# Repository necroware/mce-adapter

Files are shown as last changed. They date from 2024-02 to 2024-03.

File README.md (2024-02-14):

# MCE Adapter (Prototype!)

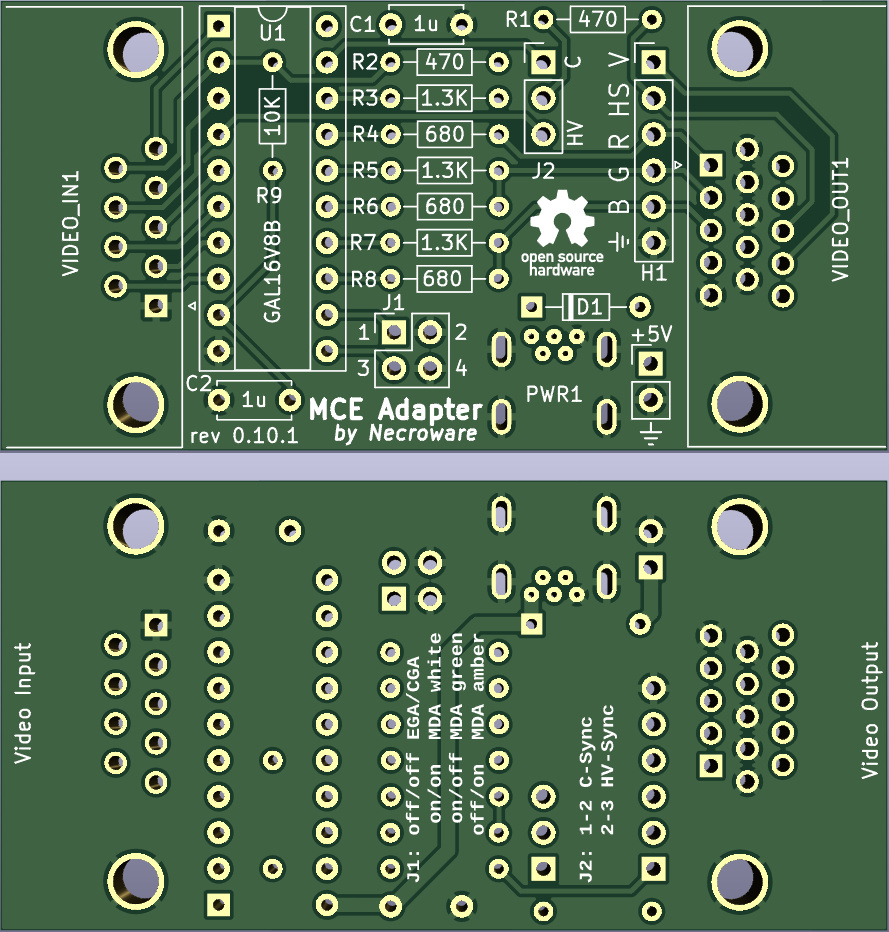
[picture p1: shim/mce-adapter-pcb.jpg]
MCE Adapter


The MCA-Adapter is a device, which can convert MDA (and Hercules), EGA and CGA
to analogue RGBS signal. It supports following features.

- Converts digital MDA, Hercules, CGA and EGA to analog RGBS or RGBHV/VGA signal
- Color DAC for 3, 4, 16 and 64 color modes
- Switchable composite sync from H- and V-Sync
- Loop through HV-Sync, colors conversion only mode
- Includes IBM's "brown-hack"for CGA and 16-colors EGA modes
- Hi/Low resolution EGA mode autodect for proper color representation
- Switchable green, white and amber monochrome screen emulation

Youtube Videos:
- Part 1: Why GBS-8200 is not a CGA/EGA converter https://youtu.be/7c3yLX52ZEs
- Part 2: Theory and implementation https://youtu.be/aUFKB4b5KpE
- Part 3: Showtime https://youtu.be/F1685u-QQ0k

## Why did I make this?

Because why not? I wanted to get some practice with EDA and I needed such an
adapter to test some of my old graphics cards.

## Why might somebody need this?

If you want to connect your old PC with MDA, CGA or EGA graphics to a more
modern VGA display, it's going to be difficult. First of all, this old graphics
standards are digital, so RGB information is sent as a bunch of 1 and 0. VGA on
the other hand understands only analogue signals, so f.e. the intensity of the red
color is defined by some value between two voltages and not by a discrete value.
So the first job of this adapter is to translates digital video signals into
analogue video signals. However, this is may be not enough, since the horizontal
sync signal of the old video standards is not supported by a usual VGA monitor.
For this purpose, a very famous upscaler named GBS-8200 and compatible can be
used to convert the sync signal to VGA compatible level.  However, GBS-8200
expects such called composite sync signal, where horizontal and vertical sync
signals are combined. This is, where this adapter comes into place, it doesn't
only convert digital RGB signal to analogue, but also composite sync signal from
incoming horizontal and vertical signals. Long story short, you will need this
adapter to connect a MDA, CGA or EGA graphics card to an analogue RGB monitor,
either by using GBS-8200 converter or the adapter standalone, in case your
monitor supports horizontal frequencies down to 15kHz.

## Why didn't I take an existing solution?

Well, first of all, I wanted to gain some experience in this. Second, I actually
was heavily inspired by a YouTube video by TheRasteri, where he evaluates the
output possibilities of an old PC, talks about the technical background and
creates his own adapter. You can see the video here:

* Part 1: https://www.youtube.com/watch?v=kHhpTq-WSJk
* Part 2: https://www.youtube.com/watch?v=vwKA1z8tg1g

As I saw his solution with a ROM, I instantly thought, that the same thing can
be done using a programmable logic IC, like GAL16V8. It would have some benefits
in timing behaviour over a solution with ROM and be also very flexible. So, here
it is.

## Which modes does it support?

The adapter can convert MDA, Hercules, CGA, 16 colors EGA and 64 colors EGA to
standard VGA (RGBHV) or RGBS (combined HV-sync). The sync output frequency is
always the same as the input frequency. The adapter can only compose HV-sync,
but doesn't actively change it. The digital color signal is converted to analogue
color signal, so any analogue RGB monitor should understand it.

## Jumpers and switches

ATTENTION: Jumper settings changed compared to previous revisions 

Color mode selection J1:
Mode                       | 1-2 | 3-4 
---------------------------|-----|-----
CGA/EGA (15kHz / 21kHz)    | OFF | OFF 
MDA/Hercules white (18kHz) | ON  | ON
MDA/Hercules green (18kHz) | ON  | OFF
MDA/Hercules amber (18kHz) | OFF | ON

Sync selectiom J2:
Mode               | Setting
-------------------|----------
HV-Sync (VGA)      | 1-2
C-Sync (Composite) | 2-3

## How to use this stuff?

1. Take the gerber files and make a PCB.
2. Assemble the board
3. Compile code/mceplug.eqn using EQN2JED tool
4. Write the compiled jed file to a GAL16V8 IC
5. Put it into the board and connect the cables
   f.e. CGA -> MCE Adapter -> GBS-8200 -> Analog RGB Monitor

## Bill of materials

Reference  |#  |LCSC    |Description
-----------|---|--------|-------------------------------------
C1 C2      |2  |C2839237|capacitor 1µF
D1         |1  |C402218 |diode 1N5819
H1         |1  |C492405 |pin header 1x6
J1         |1  |C492419 |pin header 2x2
J2         |1  |C429954 |pin header 1x3
PWR1       |1  |C46398  |USB-B mini port
PWR2       |1  |C152154 |pin header 1x2 (+5V connector)
R1 R2      |2  |C119317 |resistor 470 Ohm
R3 R5 R7   |3  |C2848597|resistor 1.3k Ohm
R4 R6 R8   |3  |C119320 |resistor 680 Ohm
R9         |1  |C173139 |resistor 10k Ohm
U1         |1  |C6509   |GAL16V8B (or compatible)
VIDEO_IN1  |1  |C141882 |DB9 female connector (MDA/EGA/CGA)
VIDEO_OUT1 |1  |C75754  |DIB15 female connector (VGA)

## Tested with following monitors
- GBS-8200 with original hardware (only 15kHz modes work)
- GBS-8200 with gbs-control firmaware (Hercules and hi-res EGA sync unstable)
- NEC Multisync LCD1970NX 19" TFT (everything works fine, Hercules is not in full screen, but works stable)
- EIZO L365 15" TFT (only Hi-Res EGA works, doesn't support 15kHz CGA nor 50Hz Hercules)
- Benq BL702A

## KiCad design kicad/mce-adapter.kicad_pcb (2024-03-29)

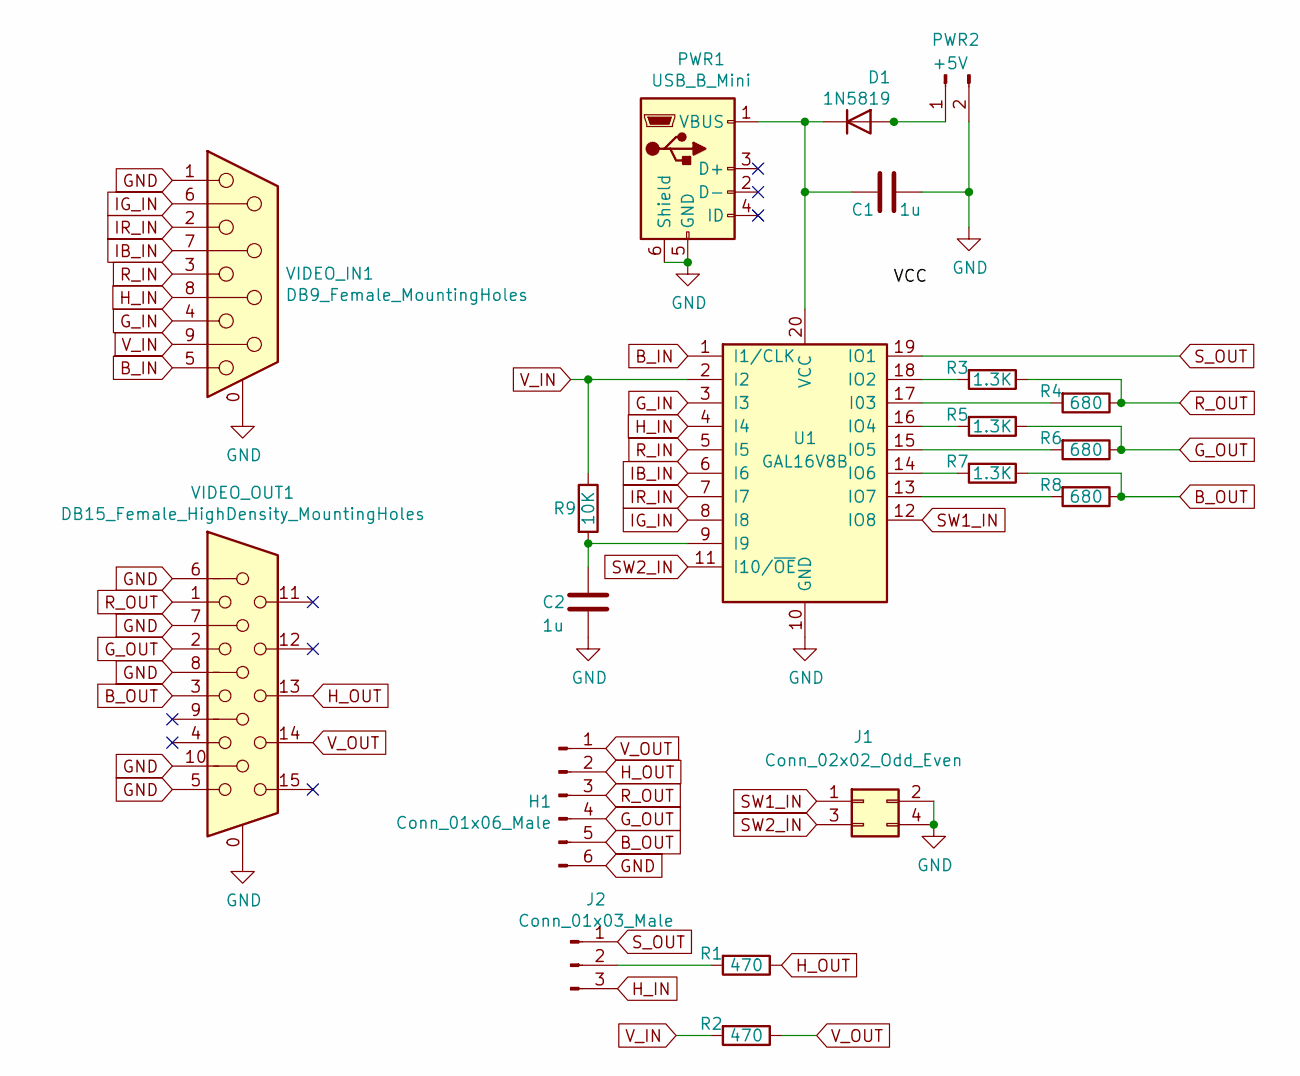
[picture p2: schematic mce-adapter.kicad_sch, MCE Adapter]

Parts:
C1, C2: 1u; C_Disc_D5.0mm_W2.5mm_P5.00mm; LCSC C2839237
D1: 1N5819; D_DO-34_SOD68_P7.62mm_Horizontal; LCSC C402218
H1: Conn_01x06_Male; PinHeader_1x06_P2.54mm_Vertical; LCSC C492405
J1: Conn_02x02_Odd_Even; PinHeader_2x02_P2.54mm_Vertical; LCSC C492419
J2: Conn_01x03_Male; PinHeader_1x03_P2.54mm_Vertical; LCSC C429954
PWR1: USB_B_Mini; USB_Mini-B-Jing_Extension_LSCS_C46398; LCSC C46398
PWR2: +5V; PinHeader_1x02_P2.54mm_Vertical; LCSC C152154
R1, R2: 470; R_Axial_DIN0204_L3.6mm_D1.6mm_P7.62mm_Horizontal; LCSC C119317
R3, R5, R7: 1.3K; R_Axial_DIN0204_L3.6mm_D1.6mm_P7.62mm_Horizontal; LCSC C2848597
R4, R6, R8: 680; R_Axial_DIN0204_L3.6mm_D1.6mm_P7.62mm_Horizontal; LCSC C119320
R9: 10K; R_Axial_DIN0204_L3.6mm_D1.6mm_P7.62mm_Horizontal; LCSC C173139
U1: GAL16V8B; DIP-20_W7.62mm_Socket; LCSC C6509
VIDEO_IN1: DB9_Female_MountingHoles; DSUB-9_Female_Horizontal_P2.77x2.84mm_EdgePinOffset7.70mm_H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; LCSC C141882
VIDEO_OUT1: DB15_Female_HighDensity_MountingHoles; DSUB-15-HD_Female_Horizontal_P2.29x1.98mm_EdgePinOffset8.35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; LCSC C75754

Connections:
B_IN: U1.1 (I1/CLK), VIDEO_IN1.5
B_OUT: H1.5, R7.1, R8.1, VIDEO_OUT1.3
GND: C1.2, C2.2, H1.6, J1.2, J1.4, PWR1.5 (GND), PWR1.6 (Shield), PWR2.2, U1.10 (GND), VIDEO_IN1.0 (PAD), VIDEO_IN1.1, VIDEO_OUT1.0, VIDEO_OUT1.5, VIDEO_OUT1.6, VIDEO_OUT1.7, VIDEO_OUT1.8, VIDEO_OUT1.10
G_IN: U1.3 (I3), VIDEO_IN1.4
G_OUT: H1.4, R5.1, R6.1, VIDEO_OUT1.2
H_IN: J2.3, U1.4 (I4), VIDEO_IN1.8
H_OUT: H1.2, R1.1, VIDEO_OUT1.13
IB_IN: U1.6 (I6), VIDEO_IN1.7
IG_IN: U1.8 (I8), VIDEO_IN1.6
IR_IN: U1.7 (I7), VIDEO_IN1.2
unnamed: D1.2 (A), PWR2.1
unnamed: C1.1, D1.1 (K), PWR1.1 (VBUS), U1.20 (VCC)
unnamed: J2.2, R1.2
unnamed: R4.2, U1.17 (I03)
unnamed: C2.1, R9.2, U1.9 (I9)
unnamed: R3.2, U1.18 (IO2)
unnamed: R5.2, U1.16 (IO4)
unnamed: R6.2, U1.15 (IO5)
unnamed: R7.2, U1.14 (IO6)
unnamed: R8.2, U1.13 (IO7)
R_IN: U1.5 (I5), VIDEO_IN1.3
R_OUT: H1.3, R3.1, R4.1, VIDEO_OUT1.1
SW1_IN: J1.1, U1.12 (IO8)
SW2_IN: J1.3, U1.11 (I10/~OE)
S_OUT: J2.1, U1.19 (IO1)
V_IN: R2.2, R9.1, U1.2 (I2), VIDEO_IN1.9
V_OUT: H1.1, R2.1, VIDEO_OUT1.14

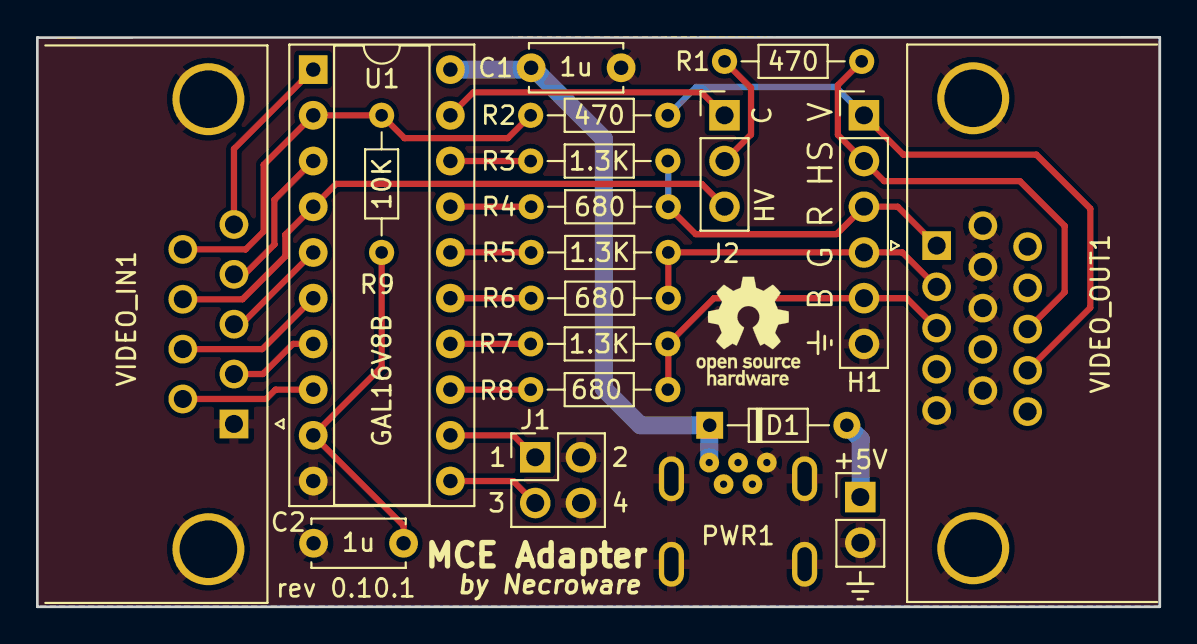
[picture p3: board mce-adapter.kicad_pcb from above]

Board: 2 copper layers, 62.4 x 31.6 mm, 20 parts (0 on the bottom side), 27 nets.

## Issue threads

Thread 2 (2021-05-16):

Add documentation for compiling and programming

wsuchy, 2021-05-16:
It would be useful to have the README file include at least the name of the basic tool chain and programmer
for the GAL chip.

necroware, 2021-05-16:
The name of the tool is included in the readme already, its EQN2JED. It's a tool, which you usually have to pay for, but ask google and may be it will tell you how to work around this problem ;) I wrote my own compiler for for the GAL, but it still doesn't support some features and is not yet well tested. May be one day I'll find the time to get it in shape and open source it. As for the programmer, there are hundreds of devices. I'm using TL866II+, but you are not limited by that. Just use whatever you have.

necroware, 2021-05-16:
Oh, almost forgot it, if you don't know how to compile the code, just use the compiled file from the release. You don't have to mess around with EQN2JED, if you don't want to change anything.

wsuchy, 2021-05-19:
Great, thank you for clarifying! BTW You could do a series about GALs on YouTube as I couldn't find any decent tutorial for beginners. I think that FPGAs have replaced them in the modern world.

necroware, 2021-05-19:
Yes GALs were replaced by FPGAs in most cases. But you still need GALs, if you work with retro hardware, that's why I was tinkering a lot with them. Yes, may be I'll do a special on GALs one day....

Closed 2021-05-19.

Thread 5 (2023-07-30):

1N5819 VIA's are not large enough. VGA Connector row spacing incorrect, Cap Incorrect

oXL0C0Xo, 2023-07-30:
Couple issues that I noticed while trying to build this.

The VIA's for the 1N5819 are too small, they should be the same size as the hole for the pin header or socket. I have ordered 2 different 1N5819 and both of them have thicker leads than a 1/4w resistor

The footprint for the VGA connector is incorrect, the rows of 5 are too close together, unless you are using some type of uncommon connector that I cant find.

The capacitor that you have listed in the BOM is 10x13 with 5mm lead spacing. The footprint on the PCB is 5mm diameter with a 2.5mm lead spacing

Appreciate your work on this project! Thanks again!

19MiRa90, 2023-08-03:
My 1N5819 fits.
There are 2 different D-SUB HD Socket. If you have not the smaller one you can push the outer pins 1-2mm to the inner
Use any very small one, 10-100µF is ok.

oXL0C0Xo, 2023-08-06:
I didn't need help with hacks to make it work, I was just pointing out the issues I encountered in case someone capable of fixing the issues wants to do it for the next guy before they order the incorrect parts. Regardless if there are other parts that work, the part numbers in the BOM are incorrect.

SteveGuidi, 2023-10-15:
> Regardless if there are other parts that work, the part numbers in the BOM are incorrect.

Just came across this post before ordering components -- has the BOM has been updated with parts that fit the footprints on the PCB?

SteveGuidi, 2023-11-23:
I redrew the PCB in EasyEDA and corrected the footprints noted in this thread; see link to project below.  I also replaced the mini-USB connector with a similar-sized micro-usb for personal preference.

Sorry, I'm not familiar with the KiCad stack and there were several non-trivial updates needed for the project to work with the current version.

https://oshwlab.com/sguidi/mce-adapter

necroware, 2024-02-14:
I took the default VGA port footprint from KiCad and it seems to be slightly off indeed. Nothing critical, but a little bit fiddly when inserting the port indeed. I slightly readjusted the footprint on the next revision.

Closed 2024-02-14.

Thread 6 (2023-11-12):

Potential improvement: power to VGA pin 9 for SCART blanking

SanguineBrah, 2023-11-12:
If you ever make another revision of this board, it might be worth adding a jumper to enable/disable sending 5v to pin 9 of the VGA connector. This would make it possible to use a VGA to SCART cable with a 100ohm resistor to the SCART RGB blanking pin (16) to deliver CGA to a standard European television.

This should be implemented as a jumper because there are reported to be some rare older monitors from when pin 9 was a key pin that mistakenly ground it rather than leaving it N/C.

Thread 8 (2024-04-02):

Potential improvement: selectable sync-on-green output

Leo-PL, 2024-04-02:
This would allow for easier connecting to scaler devices other than GBS8200, which sometimes have a RGB on triple-RCA component video connector, accepting either RGB or YPbPr.

While the latter is overkill, due to requiring high-speed video opamps to convert that, sync-on-green can be done with two transistors and some passives. Then, any cheap VGA-to-3RCA adapter normally used for YPbPr input should work with that.

I plan to connect a small external circuit to the pin-header exposing the signals as a PoC - and if it works out, I can implement that on the board and submit a PR.

Leo-PL, 2024-04-04:
I did a little testing today, and it won't be as easy. This is because black level at the output is at 0V because of lack of bias - so even if I add transistor to shunt the signal when the extracted composite sync is active, there is nothing to shunt. I'll probably try to bodge on some resistors to +5V, to shift the black level and if that works out, try to add this to board design, most likely implementing #6 as well, as I'd like to use SCART-equipped displays too.

Leo-PL, 2024-04-05:
I did some more digging around, and it seems that RGB (or YPbPr) with sync-on-green in general uses negative pulses to indicate sync, so this is better off done with an external device.

Closed 2024-04-05.

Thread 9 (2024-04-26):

Production via PCBWay is not possible

oe3gwu, 2024-04-26:
I got this email today. I wanted 5 (min qty) of those adapters fully assembled.

Could you please update your BOM File please?

```
Hi,
Thank you for choosing PCBWay! I'm your sales representative.
There is a question for you about your inquiry:
The part number in your BOM file is uncompleted, so we can't quote for you according to this file.
Could you pls complete them and send the file to us again?
There is a sample BOM file attached for reference.
Thank you and look forward to your reply!
2024-04-26
-----------------------------------
Best Regards
Kingsely

Customer Service Executive
PCBWay Production Range: PCB/PCB Assembly/Components Purchasing/CNC/3D Printing
[Skype: live:cqq13706811944](skype:Pcbwayservice03) | [Tel:86-571-8](tel:86-571-85317569)7093808
Email: [service22@pcbway.com](mailto:service03@pcbway.com)| Register: www.pcbway.com/2p
Mon.-Fri. 9:00-12:00,13:30-18:00; Sat. 9:00-12:00 (China, UTC/GMT +8.00)
```

Closed 2025-02-03.

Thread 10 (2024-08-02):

Auto mode detection filter doesn't work in CGA mode for C-Sync with C2=1uF

yngwiechou, 2024-08-02:
It seems C2 = 1uF is too low for C-Sync to work properly.

Please see attached graph
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

Apology for not able to test MDA and Enhanced EGA, since I don't have them in hand.

Liz1701, 2025-01-31:
Hi, I don't understand all the technical stuff.  I built one of these from kit.  I have an LCD that works with the 15khz RGBHV.  However I'm wandering if I'm having the C-Sync Issue you describe?  My purpose in getting the MCE adapter was to connect my Sony PVM1350.  But it apparently isn't detecting the RGBs 15khz.  This is using CGA.

oXL0C0Xo, 2025-02-03:
Has anyone tested if swapping the capacitor at C2 with a 4.7uf resolves the issue without any negative effects on anything else?

necroware, 2025-02-09:
I tested 4.7uf and it seems to work fine. Other features were not affected. Color mode auto-detection works fine.

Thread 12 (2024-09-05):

CGA, Hi-res EGA detection doesn't work.

A-Small-Mice, 2024-09-05:
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

I used the MCE adapter with an IBM EGA card.

The IBM EGA card's jumper settings are set to EGA monitor.

necroware, 2025-02-03:
This one could be a duplicate of #10

A-Small-Mice, 2025-02-07:
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

Thank you for answering my question. Since it has been quite a long time since I raised this issue, I took a moment to think about why I determined that the EGA detection was not functioning correctly.

It is probably because there is a difference between the images in the demonstration video you uploaded and mine. When comparing my image with yours, I can see that some colors are missing in my image.

necroware, 2025-02-07:
Ok, that looks odd indeed. I didn't realize it on the previous image. Which firmware and adapter version did you use? I just tried the latest release and couldn't reproduce the issue. This is definitely not related to Hi-Res EGA detection, because we can clearly see that the brown colors are right. That is a reliable sign for working automatic mode switching. So there has to be something else what is wrong, but currently I don't know what exactly.

Can you play with contrast settings of your monitor? Do you see more/less pixels if you adjust  that?

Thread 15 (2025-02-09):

TTL signal level for sync signals

necroware, 2025-02-09:
On VGA the color signals are analog values between 0V and 0.7V (actually all monitors are at least 1V tolerant) but the HV-Sync values should be at TTL levels between 0V and 5V. Unfortunately some devices are not 5V tolerant and could be damaged over time when using normal TTL levels. One of such devices is GBS-8200, which is only 3.3V tolerant.

In the past I experimented with different levels and it tuned out that all of the monitors and converters which I tested did actually work with the same levels for colors and sync signals with up to 1V, so I've chosen the resistors accordingly to stay under 1V for all signals.

Recently I saw slight instability on the H-Sync on some monitors when the computer attached was under load. A slight blurry shift at particular frequency. This is most probably because the H-Sync gets disturbed/unstable. Probably this can be mitigated by raising voltage levels of the sync signals.

Going up to 5V would be VGA specification conform, but as I wrote, some devices don't like it. The best would be to try to stay below 3.3V. This can be achieved by replacing 470 Ohm resistors R1 and R2 with 33 Ohm values.

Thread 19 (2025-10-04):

Self Powered from rectified sync signals

pgodwin, 2025-10-04:
Curious if you've considered making the device self-powered by rectifying the sync signals? Similar to https://www.mikesarcade.com/wiretap/info/SyncInv.pdf

I have it ago and seem to get about 4V from HS and VS but it looks like the current design draws about 20mA which is too high. So thinking something like the ATF16LV8C could be used instead and provide a great operating voltage range.

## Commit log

2020-10-15 Added rev0.5
    [Gerber_BoardOutline.GKO, Gerber_BottomLayer.GBL, Gerber_BottomSolderMaskLayer.GBS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]
2020-10-15 Add revision 0.6
    [Gerber_BoardOutline.GKO, Gerber_BottomLayer.GBL, Gerber_BottomSolderMaskLayer.GBS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]
2020-10-16 Moved all gerber files into a zip archive
    [mce-adapter-bom.csv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]
2020-11-23 Switched to KiCad and regenerated output
    [mce-adapter-bom.csv, mce-adapter.kicad_pcb, mce-adapter.sch]
2020-11-23 Move gerber folder into kicad subfolder
    [mce-adapter-B_Cu.gbr, mce-adapter-B_Mask.gbr, mce-adapter-B_Paste.gbr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]
2020-11-23 Add necroware kicad library
    [mce-adapter.kicad_pcb, mce-adapter.sch]
2020-11-23 Regenrated gerber files
    [mce-adapter-B_Cu.gbr, mce-adapter-B_Mask.gbr, mce-adapter-B_Paste.gbr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]
2020-11-23 Vastly shrink PCB
    [mce-adapter-B_Cu.gbr, mce-adapter-B_Mask.gbr, mce-adapter-B_Paste.gbr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]
2020-11-23 Move USB slightly over the edge
    [mce-adapter-B_Cu.gbr, mce-adapter-B_Mask.gbr, mce-adapter-B_Paste.gbr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]
2020-11-23 Update LSCS part number
    [mce-adapter.sch]
2020-11-25 Update LCSC part numbers
    [mce-adapter.sch]
2020-12-06 Reajust some resistors improve layout
    [mce-adapter.kicad_pcb, mce-adapter.sch]
2020-12-06 Update BOM
2020-12-08 Move parts away from VGA out.
    Add some back face silk notations
    [mce-adapter.kicad_pcb, mce-adapter.sch]
2020-12-08 Add on silk documentation
    [mce-adapter.kicad_pcb]
2020-12-08 Update pcb image
2020-12-08 Pull PWR1 from the edge inwards
    [mce-adapter.kicad_pcb]
2020-12-08 Regenerate gerber files
    [mce-adapter-B_Cu.gbr, mce-adapter-B_Mask.gbr, mce-adapter-B_Paste.gbr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]
2021-02-03 Update README.md
    R8 does not need to be a 3W resistor. Standard 1/4W should be fine.
2021-02-05 Fix too short board under VGA output
    [mce-adapter.kicad_pcb]
2021-02-05 Remove the gerber files from the project.
    The gerber files will be deployed in release only
    [mce-adapter-B_Cu.gbr, mce-adapter-B_Mask.gbr, mce-adapter-B_Paste.gbr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]
2024-01-29 Readjusted resistor values, updated to version 0.7.2
    [mce-adapter.kicad_pcb, mce-adapter.sch]
2024-01-29 Re-added DIP switch, rev. 0.8.0
    [mce-adapter.kicad_pcb, mce-adapter.sch]
2024-01-29 Fixed GAL name
    [mce-adapter.kicad_pcb, mce-adapter.sch]
2024-01-29 Switched to KiCad 7
    [mce-adapter.kicad_pcb, mce-adapter.kicad_sch, mce-adapter.sch]
2024-01-31 Added mode auto-detection
    [mce-adapter.kicad_pcb, mce-adapter.kicad_sch]
2024-02-13 Readjusted resistor networks to get blow 0.7V
    [mce-adapter.kicad_pcb, mce-adapter.kicad_sch]
2024-02-14 Update readme and LCSC parts
    [mce-adapter.kicad_sch]
2024-03-29 Updated project to KiKad 8.0
    [mce-adapter.kicad_pcb, mce-adapter.kicad_sch]
